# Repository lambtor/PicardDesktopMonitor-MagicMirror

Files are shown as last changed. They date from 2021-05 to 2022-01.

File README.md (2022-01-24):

# PicardMonitor

This project is my attempt to build an LCARS kiosk using a copy of the <a href='https://github.com/MichMich/MagicMirror'>MagicMirror project</a>.<br><br>

<a href='https://youtu.be/VpyOh2fm7kE'>Youtube Functionality Demo</a><br><br>

At its simplest, this is a highly customized fork of their project.  There are several hardware buttons mapped to keyboard buttons to trigger multiple actions:
<ul>
	<li>Screen blanking (set power pin to off while keeping pi on) via Pause key</li>
	<li>Theme changes (tng / ds9 / voy / red alert) via T/N, D, V, R "keyboard" buttons respectively.</li>
	<li>Full page refresh (control+F5)</li>
	<li>Close magic mirror browser window and tell pi to shutdown (via Insert key)</li>
</ul> All key actions are defined and executed with teensyLC, but shutdown and sounds are handled by mapping related keyboard buttons in hp-keypress.py, which is configured as a service on the pi.  hp-keypress.py relies on <a href="https://github.com/boppreh/keyboard">https://github.com/boppreh/keyboard</a> library.<br><br>

This version is intended to run on a raspberry pi zero with a hyperpixel screen.  To get magicMirror running on a Pi Zero, I used this guide: https://www.linuxscrew.com/raspberry-pi-magic-mirror
<br>Many of the modules have been heavily modified, and the assembly of hardware is completely custom / original. Anyone attempting to build one of these should have some comfort level with soldering or assembling pi hardware.  I highly recommend that anyone building one of these should have a high comfort level with javascript programming & html / css manipulation.<br><br>

General issues to be aware of even after software setup is complete:<br>
<ul>
	<li>Mouse Button click sounds may not play from MMM-Sounds. This is usually due to an issue with a library not loading properly on page start, and can often be fixed with a control-F5 (hold main teensy button down for ~3 seconds to force full page refresh).</li>
	<li>Sounds may not play at all.  This can be an issue with pulse audio, and you may need to modify a config file to use the correct device as default.  See https://shallowsky.com/linux/pulseaudio-command-line.html for pulse audio management via command line.</li>
	<li>Not all areas of screen will be full of data on initial load, if you have not set up the config.js file for Magic Mirror.  You will need to set a location for date and weather, and you will need an API developer key for openweather. See https://docs.magicmirror.builders/modules/weatherforecast.html#configuration-options. News RSS feeds will need to be defined.</li>
	<li>Transit information was heavily modified by me for my own use, and will likely not apply to your location.  You will need to install an existing MagicMirror module for the transit data you want to see.  Scrolling transit data uses a modified MMM-HTTPRequestDisplay module, but you will need to modify a transit detail module on your own.  My train detail module has 2 separate definitions for train lines, both set to position "bottom-right". Train detail section was built with the following HTML structure:
	<ul>
		<li>outer div</li>
		<li>table of results (4 columns and 3 rows), with leftmost column showing name of stop. The top leftmost cell has a rowspan equal to number of train detail rows (max of 3).  Each of the train detail records has 1 column each for time to arrival, direction of train (end stop), and train type (line name).</li>
		<li>You'll need to modify your train/bus detail module to mimic the structure I'm using if you want it to have the style you want. See Modules/trainAndBusDetail for a non-functional js file showing the structure I am using.</li>
	</ul>
	</li>
</ul>

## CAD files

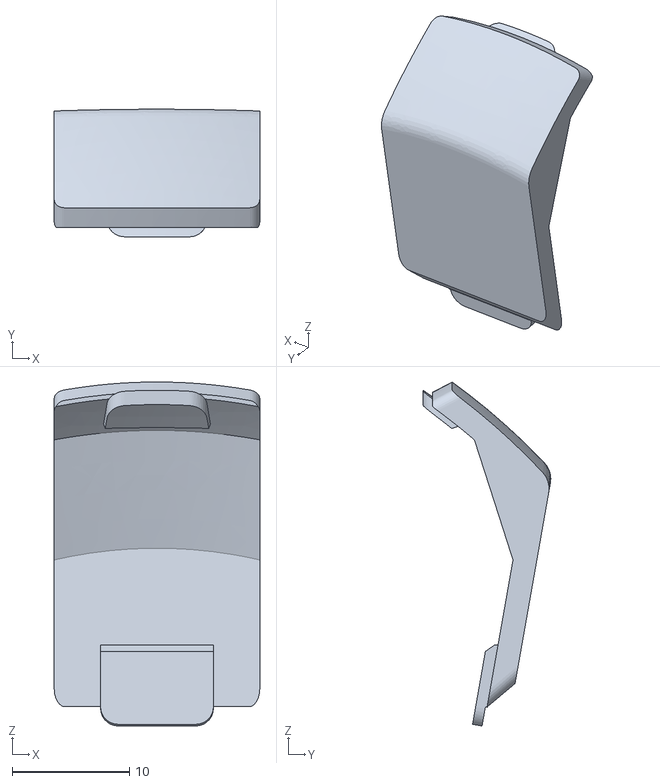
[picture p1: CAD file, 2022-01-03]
MiniShellModels/mainButton.stl
17.5 x 10.9 x 29.3

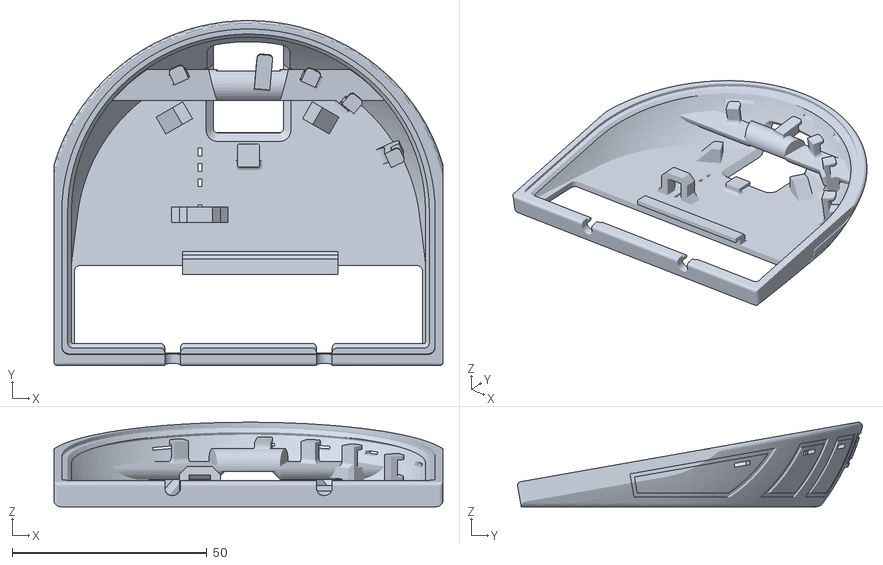
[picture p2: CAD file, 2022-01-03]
MiniShellModels/baseTop-laidFlatStenciled.stl
100.0 x 88.7 x 21.7

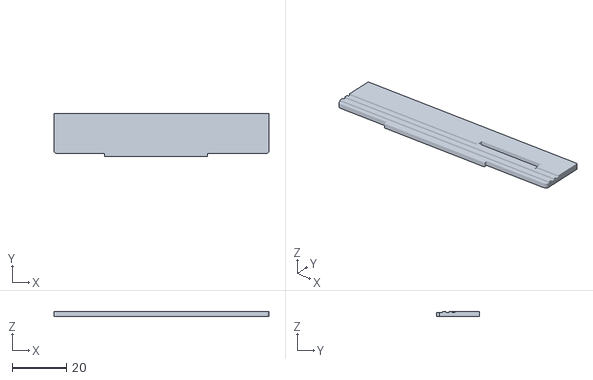
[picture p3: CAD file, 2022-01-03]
MiniShellModels/screenFrameTab.stl
79.5 x 16.0 x 2.00

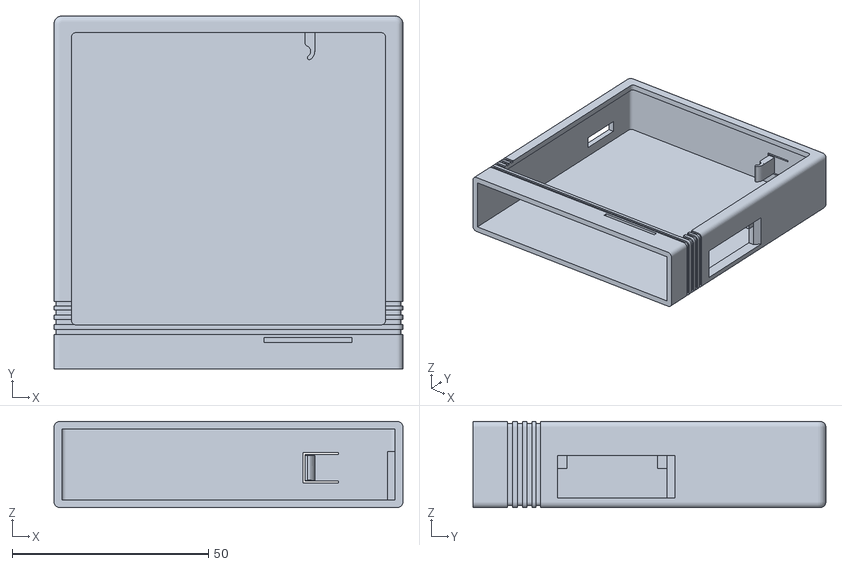
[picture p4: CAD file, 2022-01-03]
MiniShellModels/screenFrame-backNotched.stl
89.0 x 90.0 x 22.0

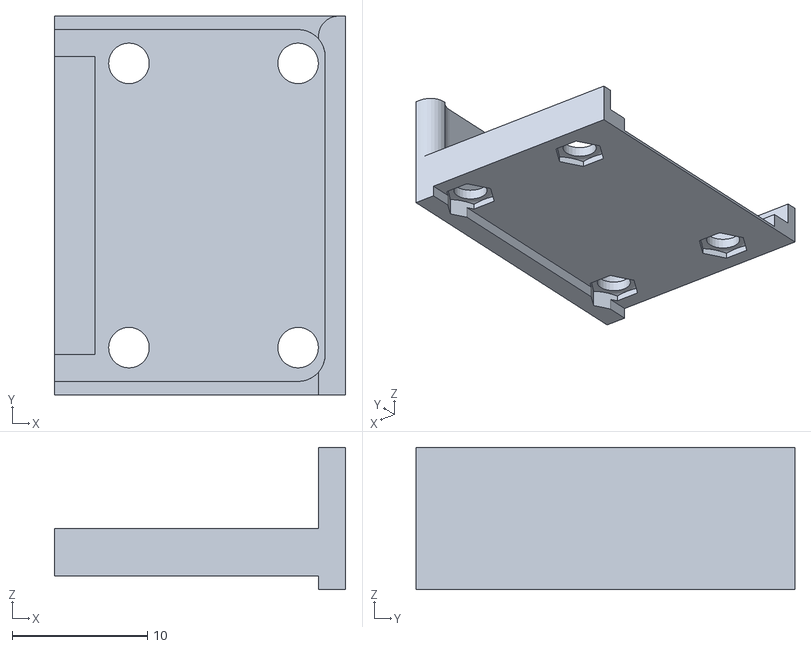
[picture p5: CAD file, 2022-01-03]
MiniShellModels/cameraTray.stl
21.5 x 28.0 x 10.5

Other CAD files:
MiniShellModels/screenFrame.stl

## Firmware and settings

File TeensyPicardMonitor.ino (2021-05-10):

#include <Bounce.h>
//#include <Keyboard.h>

//single keypress is print screen button
//held for 2-5 seconds => full refresh of page or "restart"
//held for 5+ seconds => shutdown machine
//KEY_PAUSE				toggle display power on/off
//KEY_SCROLL_LOCK		close magic mirror and shutdown system -> 
//scrlk in keyboard python script
//						send keyboard alt+F4, then 
//						os.system("sudo shutdown -P now")
//KEY_PRINTSCREEN		refresh magicmirror (control + F5)
//prnt scrn, prtscn, print screen
//in python interface
//notes on audio - pulse audio needs to have the proper device configured as default using device name, not sink #
//sink number can work, but numbers seem to get randomly assigned at startup. 
//sound issue is either this or just problem with loading all audio script libraries. often this problem goes away after using control+F5 to reload/restart mirror from browser window
//sudo alsamixer
//sudo alsactl store **this stores alsamixer settings like volume control**

#define KEYMAP_MAIN		KEY_PAUSE
#define KEYMAP_SECOND	KEY_SCROLL_LOCK	
#define KEYMAP_THIRD	KEY_INSERT
#define CTRL_KEY		MODIFIERKEY_CTRL
#define ALT_KEY			MODIFIERKEY_ALT
#define F4_KEY			KEY_F4
#define F5_KEY			KEY_F5
#define N_KEY			KEY_N
#define D_KEY			KEY_D
#define V_KEY			KEY_V
#define R_KEY			KEY_R

#define PIN_BUTTON0		23
#define PIN_BUTTON1		22
#define PIN_BUTTON2		21
#define PIN_BUTTON3		24
#define PIN_BUTTON4		25
#define PIN_BUTTON_SD	0

//teensy lc can use pins 16,17,20,22,23 or 3 and 4 for analogWrite commands
#define PIN_LED1		16
#define PIN_LED2		17

#define LED_BRIGHTNESS	32

//#define F5_KEY			KEY_A
//#define KEYMAP_MAIN		KEY_M
//#define KEYMAP_THIRD	KEY_D

// Create Bounce objects for each button.  The Bounce object
// automatically deals with contact chatter or "bounce", and
// it makes detecting changes very simple.
//Main button uses pin 23
Bounce button0 = Bounce(PIN_BUTTON0, 30);

Bounce button1 = Bounce(PIN_BUTTON1, 30);  // 10 = 10 ms debounce time as 2nd parameter. 1st parameter is digital pin #
Bounce button2 = Bounce(PIN_BUTTON2, 30);
Bounce button3 = Bounce(PIN_BUTTON3, 30);
Bounce button4 = Bounce(PIN_BUTTON4, 30);
Bounce buttonSD = Bounce(PIN_BUTTON_SD, 30);


unsigned long mnButtonStart	= 0;
unsigned long mnButtonEnd = 0;

void setup() {
	// Configure the pins for input mode with pullup resistors.
	// The pushbuttons connect from each pin to ground.  When
	// the button is pressed, the pin reads LOW because the button
	// shorts it to ground.  When released, the pin reads HIGH
	// because the pullup resistor connects to +5 volts inside
	// the chip.  LOW for "on", and HIGH for "off" may seem
	// backwards, but using the on-chip pullup resistors is very
	// convenient.  The scheme is called "active low", and it's
	// very commonly used in electronics... so much that the chip
	// has built-in pullup resistors!

	pinMode(PIN_BUTTON0, INPUT_PULLUP);

	pinMode(PIN_BUTTON1, INPUT_PULLUP);
	pinMode(PIN_BUTTON2, INPUT_PULLUP);
	pinMode(PIN_BUTTON3, INPUT_PULLUP);
	pinMode(PIN_BUTTON4, INPUT_PULLUP);
	pinMode(PIN_BUTTON_SD, INPUT_PULLUP);

	pinMode(PIN_LED1, OUTPUT);
	pinMode(PIN_LED2, OUTPUT);
	
	analogWrite(PIN_LED1, LED_BRIGHTNESS);
	analogWrite(PIN_LED2, LED_BRIGHTNESS);

	mnButtonStart = millis();
}

void loop() {
	// Update all the buttons.  There should not be any long
	// delays in loop(), so this runs repetitively at a rate
	// faster than the buttons could be pressed and released.
	button0.update();
	//theme button statuses (base outer perimeter)
	button1.update();
	button2.update();
	button3.update();
	button4.update();
	//shutdown button status
	buttonSD.update();

	// Check each button for "falling" edge.
	// Type a message on the Keyboard when each button presses
	// Update the Joystick buttons only upon changes.
	// falling = high (not pressed - voltage from pullup resistor)
	//           to low (pressed - button connects pin to ground)
	if (button0.fallingEdge()) {
		//Keyboard.press(KEYMAP_MAIN);
		mnButtonStart = millis();
	}
	if (button1.fallingEdge()) {
		Keyboard.press(N_KEY);
	}
	if (button2.fallingEdge()) {
		Keyboard.press(D_KEY);
	}
	if (button3.fallingEdge()) {
		Keyboard.press(V_KEY);
	}
	if (button4.fallingEdge()) {
		Keyboard.press(R_KEY);
	}
	
	if (buttonSD.risingEdge()) {
		Keyboard.press(KEYMAP_SECOND);
	}

	//4 theme triggers and 1 direct shutdown button
	/* N	D	V	R  */

	//all 4 buttons for theme changes - these are mapped to single letter keys in magic mirror
	if (button1.risingEdge()) {
		Keyboard.release(N_KEY);
	}
	if (button2.risingEdge()) {
		Keyboard.release(D_KEY);
	}
	if (button3.risingEdge()) {
		Keyboard.release(V_KEY);
	}
	if (button4.risingEdge()) {
		Keyboard.release(R_KEY);
	}

	if (buttonSD.risingEdge()) {
		Keyboard.release(KEYMAP_SECOND);

		//send alt-f4 to close magic mirror first
		Keyboard.set_modifier(ALT_KEY);
		Keyboard.set_key1(F4_KEY);
		Keyboard.send_now();
		//delay ensures all systems will accept keystroke - mac osx is largest throttler
		delay(300);

		Keyboard.set_modifier(0);
		Keyboard.set_key1(0);
		Keyboard.send_now();
		delay(300);
	}

	// Check each button for "rising" edge
	// For many types of projects, you only care when the button
	// is pressed and the release isn't needed.
	// rising = low (pressed - button connects pin to ground)
	//          to high (not pressed - voltage from pullup resistor)
	if (button0.risingEdge()) {		
		mnButtonEnd = millis();
		
		//button was held down more than 2 seconds but less than 5
		if ((mnButtonEnd - mnButtonStart) > 2000) {			
			if ((mnButtonEnd - mnButtonStart) < 5000) {
				//button was held down between 2 and 5 seconds - send board refresh combo
				// press and hold CTRL
				Keyboard.set_modifier(CTRL_KEY);
				Keyboard.set_key1(F5_KEY);
				Keyboard.send_now();
				//delay ensures all systems will accept keystroke - mac osx is largest throttler
				delay(300);
				
				// release all the keys at the same instant
				Keyboard.set_modifier(0);
				Keyboard.set_key1(0);
				Keyboard.send_now();
			} else {
				//button was held more than 5 seconds - close mirror and shutdown pi
				//send alt-f4 to close magic mirror first
				Keyboard.set_modifier(ALT_KEY);
				Keyboard.set_key1(F4_KEY);
				Keyboard.send_now();
				//delay ensures all systems will accept keystroke - mac osx is largest throttler
				delay(300);
				Keyboard.set_modifier(0);
				Keyboard.set_key1(0);
				Keyboard.send_now();
				delay(300);
			
				//send shutdown trigger key
				Keyboard.press(KEYMAP_THIRD);
				//delay ensures all systems will accept keystroke - mac osx is largest throttler
				delay(300);
				Keyboard.release(KEYMAP_THIRD);
			}			
		} else {
			Keyboard.press(KEYMAP_MAIN);
			delay(300);
			Keyboard.release(KEYMAP_MAIN);
		}
		
	}
  
}	//end loop

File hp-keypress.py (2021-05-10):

#!/usr/bin/python
import time
import pigpio
import keyboard
import os
#from subprocess import call

mGPIO = pigpio.pi()
mnPauseDown = 0
mnShutdownThreshold = 3000000
mbIsDownNow = False

#print(keyboard.normalize_name("print screen"))

def oKeyHoldPress(e):
	#print("holdPress invoked")
	global mnPauseDown
	global mbIsDownNow
	if (mbIsDownNow == False and (mnPauseDown + 100000 < time.time())):
		mbIsDownNow = True
		mnPauseDown = time.time()
	#print(mnPauseDown)

def oKeyShutdown(e):
	#call(["aplay", "/home/pi/MagicMirror/modules/MMM-Sounds/sounds/tngScreenOff.wav"])
	os.system("sudo aplay /home/pi/MagicMirror/modules/MMM-Sounds/sounds/tngScreenOff.wav")
	os.system("sudo shutdown -h now")

#def oKey_Release(e):
def oKey_Release(e):
	#print("keypress invoked")
	mnBrightnessLevel = 96
	mnHyperpixelPowerPin = 19
	nCurrentBrightness = 0
	#if oPressedKey == moPauseKey:
	#pixel power pin is 19
	nCurrentBrightness = mGPIO.get_PWM_dutycycle(mnHyperpixelPowerPin)
	if nCurrentBrightness == 0:
		#call(["aplay", "/home/pi/MagicMirror/modules/MMM-Sounds/sounds/tngScreenOn.wav"])
		mGPIO.set_PWM_dutycycle(mnHyperpixelPowerPin, mnBrightnessLevel)
		os.system("sudo aplay /home/pi/MagicMirror/modules/MMM-Sounds/sounds/tngKey.wav &")
	else:
		#call(["aplay", "/home/pi/MagicMirror/modules/MMM-Sounds/sounds/tngScreenOff.wav"])
		mGPIO.set_PWM_dutycycle(mnHyperpixelPowerPin, 0)
		os.system("sudo aplay /home/pi/MagicMirror/modules/MMM-Sounds/sounds/tngKey.wav &")


#keyboard.add_hotkey('pause', oKey_Release)
keyboard.on_release_key('pause', oKey_Release)
#print screen print_screen, print all dont work
#keyboard.add_hotkey('insert', oKeyShutdown)
keyboard.on_release_key('insert', oKeyShutdown)

keyboard.wait()

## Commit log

2021-04-20 Add files via upload
    modified script to support up to 5 buttons. 5 second hold of main button no longer causes weird behavior on mirror or display toggles.
    [TeensyPicardMonitor.ino]
2025-04-10 Add files via upload
    easyeda legacy app project file for PCB
2025-04-10 Add files via upload
    exported gerber file to upload if you want to order from jlcpcb
